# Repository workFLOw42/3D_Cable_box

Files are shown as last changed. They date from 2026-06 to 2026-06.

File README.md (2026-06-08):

# Kabelbox – frei konfigurierbar (Voronoi, entnehmbare Wände)

**Eigenentwicklung** in OpenSCAD + Python. Eine Box mit **4 entnehmbaren
Voronoi-Wänden**, **glattem Schiebedeckel** und je Wand wählbarem **Kabelloch**.
Design-Vokabular wie der Zahnbürstenhalter (gerundet R5, 5-mm-Füße, Schiebe-Mechanik,
bündig/keine Überstände).

> **Entwickeln/Weiterarbeiten:** Stand, Parameter, Build-Ablauf und Stolpersteine
> stehen in **[`DEVNOTES.md`](DEVNOTES.md)**.

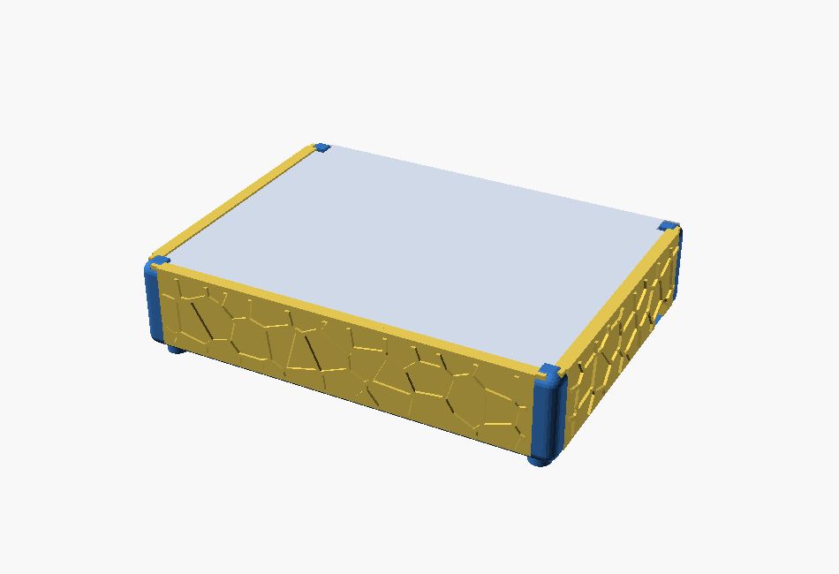
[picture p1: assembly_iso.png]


## Über dieses Projekt

**Warum gibt es die Kabelbox?**
Steckdosenleisten, Netzteile und Kabelsalat verschwinden am besten in einer Box – aber
die meisten fertigen Boxen sind in genau einer Größe gegossen und innen schlecht
zugänglich. Diese Box ist deshalb von Grund auf **frei konfigurierbar**: Breite, Tiefe
und Höhe sowie die Kabeldurchführungen werden in einer einzigen Parameterdatei
(`params.scad`) festgelegt, der gesamte Korpus skaliert automatisch mit.

**Idee dahinter.**
Die Box folgt einem bewussten Design-Vokabular (geteilt mit dem Schwester-Projekt
[„Elektrischer Zahnbürstenhalter"](https://github.com/workFLOw42/3D_OralB_Sonicare_toothbrush_holder)):
rundum **gerundete Kanten (R5)**, **bündige
Außenflächen ohne Überstände**, ein **erhabenes Voronoi-Relief** als Optik *und*
Materialersparnis sowie eine **werkzeuglose Schiebe-Mechanik**. Die vier Wände sind
einzeln **entnehmbar** und der Deckel gleitet von hinten ein – so kommt man jederzeit an
den Inhalt, ohne etwas aufzubrechen.

**Reproduzierbar statt Einmal-Export.**
Es handelt sich um eine **Eigenentwicklung**; alle Teile entstehen reproduzierbar aus
OpenSCAD-Quellen + Python-Generatoren (Voronoi, 3MF-Packen). Wer andere Maße braucht,
ändert die Parameter und baut neu – oder nutzt die MakerWorld-Einzeldatei mit Customizer.

**Status.** **Version 1.0** – funktionsfähig und gedruckt-verifiziert. Das jetzige
Aussehen ist der Startpunkt; das Projekt wird **bei Bedarf aktiv weiterentwickelt,
überarbeitet und erweitert**. Rückmeldungen, Ideen und Probedruck-Erfahrungen sind
willkommen.

## Konzept
- **Rahmen** (`box.scad`, bleibt fest): gerundeter Boden + **4 Eckpfosten** (flush
  in den Ecken) + **4 Füße**. Jeder Pfosten hat **2 senkrechte Nuten** für die
  angrenzenden Wände. Die Nuten liegen **bündig in den Pfosten** (Front-Skin) →
  nichts steht über; die Box-Außenkontur bleibt exakt B×T.
- **4 Wände** (`wall.scad`): **solide** Wand mit **erhabenem Voronoi-Relief** (wie
  Zahnbürstenhalter), gleiten senkrecht in die Pfosten-Nuten → **entnehmbar**.
  Außenfläche bündig (Relief steht – wie beim Holder – `relief_h` nach außen über).
  Je Wand optional ein **nach unten offener Kabel-Schlitz** (keins/links/mitte/rechts).
- **Deckel** (`lid.scad`): **glatte** Platte. Front/Links/Rechts tragen oben eine
  nach innen überstehende **Lippe** → der Deckel ist **3-seitig gefangen** und gleitet
  **von hinten** darunter ein. Die **Rückwand ist niedriger** (um `lid_t+lid_lip_t+
  lid_clear`) → der Deckel **läuft über die Rückwand** und schließt hinten **bündig**
  (y=box_d) ab. Oberseite leicht versenkt (unter den Lippen). Eck-Aussparungen für
  die Pfosten. *Entnahme: Deckel nach hinten herausschieben.*
- **Montage**: Wände von oben in die Pfosten-Nuten → Deckel von hinten unter die
  3 Lippen einschieben. Demontage umgekehrt.

## Maße (editierbar)
| | Wert |
|---|---|
| Box außen | **`box_w` × `box_d` × `box_h` = 200 × 150 × 41,8 mm** (+5 mm Füße) · **35 mm lichte Nutzhöhe** (Boden bis Deckel) |
| Wandstärke / Boden | 3 / 3 mm · Eckpfosten 10 mm · Kanten R5 |
| Kabel-Schlitz | `cable_w`=12 mm breit, unten offen, Oberkante `cable_h`=12 mm |

Position je Wand: **mitte** = exakt mittig; **links/rechts** = ein Lochbreiten-
Abstand zum inneren Rand.

## MakerWorld (Customizer)
Einzeldatei **`kabelbox_makerworld.scad`** hochladen (alle Module inline).
- **Maße**: `box_w` / `box_d` / `box_h`.
- **Kabelloch je Wand**: `cable_front/back/left/right` ∈ none/left/center/right.
- **Teil-Auswahl** `part`: `montage` (Vorschau) · `platte` (alle Teile nebeneinander)
  · `box` · `lid` · `wall_front/back/left/right`.

> **X2D-Hinweis**: Korpus und Deckel sind bei 200 × 150 jeweils fast plattengroß –
> sie passen **nicht gemeinsam** auf eine 256 × 256-Platte. Dann Teile einzeln
> wählen (2 Platten) **oder** die Box kleiner konfigurieren. `part="platte"` ist
> für kleinere Boxen gedacht.

## Bauen (lokal)
```
# Toolchain: OpenSCAD + Python (numpy, scipy, trimesh)
powershell -File build.ps1   # Voronoi -> STL -> 3MF -> Vorschau
```
Quelle: `params.scad` (Wahrheitsquelle) · `voronoi.scad` · `voronoi_data.scad` (auto)
· `box.scad` · `wall.scad` · `lid.scad` · `assembly.scad`. Werkzeuge: `gen_voronoi.py`,
`pack_3mf.py`, `build.ps1`.

## Drucken
- **Korpus**: offen nach oben, Füße unten – ohne Stützen.
- **Wände/Deckel**: flach liegend – ohne Stützen.
- **Spiele** nach Probedruck justieren: `rail_clear` (Wand↔Nut), `lid_clear` (Deckel).

## Lizenz

[CC BY-NC 4.0](LICENSE) – Namensnennung, keine kommerzielle Nutzung.

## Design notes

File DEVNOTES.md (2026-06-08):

# DEVNOTES – Kabelbox_frei_Konfig (Stand v1.0)

Arbeitsnotizen für die **Wiederaufnahme**. Kurz, aber vollständig.

## Status
**v1.0, funktionsfähig & verifiziert.** Eigenentwicklung (OpenSCAD + Python),
Design-Vokabular wie der Zahnbürstenhalter-Halter (`Elektr_Zahnbuerstenhalter_frei_Konfig`).

## Build / Werkzeuge
- **Build:** `powershell -File build.ps1` im Projektordner (nutzt `$PSScriptRoot`,
  also pfad-unabhängig). Erzeugt Voronoi-Daten, alle STLs, 3MF und die Vorschau.
- **Werkzeuge:** OpenSCAD (Windows-Default `C:\Program Files\OpenSCAD\openscad.exe`),
  Python mit numpy/scipy/trimesh.
- **Hinweis (lokale Eigenheit):** Wird der Ordner über OneDrive synchronisiert,
  können direkte Datei-Schreibzugriffe fehlschlagen — dann in einem lokalen Ordner
  bauen und die Ergebnisse per `Copy-Item` zurückkopieren.

## Architektur (Koordinaten: x=Breite, y=Tiefe [Front y=0, Rück y=box_d], z=Höhe)
- `params.scad` = **einzige Wahrheitsquelle** (Maße, Belegung, Feder/Nut, Deckel, Voronoi).
- `box.scad` = **Rahmen** (bleibt fest): gerundeter Boden + 4 Eckpfosten (flush) mit je
  2 senkrechten Wand-Nuten + Boden, 4 Füße. `place_wall(side)` platziert local→Seite
  (auch für Wände/Deckel genutzt). Top via `round_env()` gerundet.
- `wall.scad` = **1 entnehmbare Wand**, parametrisch je Seite. Solide + erhabenes
  Voronoi-Relief. Federn an den Enden → Pfosten-Nuten. Front/Links/Rechts: **Lippe**
  oben (`lid_lip`); **Rückwand: niedriger** (`wall_height("back")`). Kabel-Schlitz unten offen.
- `lid.scad` = **glatter Deckel**, 3-seitig unter den Lippen gefangen, hinten bündig,
  Eck-Aussparungen für Pfosten.
- `voronoi.scad` (reuse) + `voronoi_data.scad` (auto via `gen_voronoi.py`).
- `assembly.scad` (Vorschau), `pack_3mf.py`, `kabelbox_makerworld.scad` (Einzeldatei).

## Schlüssel-Parameter (params.scad)
- Maße: `box_w=200, box_d=150, box_h=41.8` (editierbar; 35 mm nutzbar Boden→Deckel),
  `wall_t=3, floor_t=3, post_sz=10, fillet_r=5`.
- Feder/Nut Wand↔Pfosten: `front_skin=1` (Skin vor Feder → flush), `tongue_d=4`,
  `rail_clear=0.3`, `rail_lead=1.2`.
- Deckel: `lid_t=2.5`, `lid_lip_t=1.0` (Lippen-Überdeckung), `lid_ov=3.0` (Lippe nach innen),
  `lid_clear=0.3`. Rückwand-Absenkung = `lid_t+lid_lip_t+lid_clear = 3.8`.
- Kabelloch: `cable_w=12`, `cable_h=12` (Oberkante über Boden), **unten offen**.
  Belegung: `cable_front/back/left/right` ∈ none/left/center/right.
  Position: center=mittig; left/right = 1 Lochbreite Abstand zum inneren Rand.
- Voronoi: `voro_seed=11, voro_cell=14, voro_strut=1.8, relief_h=1.2`.

## 1. Kiste (aktuell gesetzt, vom Nutzer bestätigt)
`cable_right="right"` (rechte Wand, Loch **hinten**, Welt-y≈122) +
`cable_back="right"` (Rückwand, Loch **links**/−x, Welt-x≈28). Front/Links = none.

## Verifiziert (contains-Tests)
- Box-Außenkontur exakt 200×150 (Füße bis z=−5) → **nichts steht über**.
- Wand-Feder sitzt in **flush** Pfosten-Nut; Front-Skin bleibt.
- (v1.1, Welt-Z am Assembly) Boden-Oberkante z=3,0; Deckel-Unterkante z=38,0
  → **35,0 mm nutzbar** (STL-Bounds verifiziert). Deckel z 38,0–40,5 (versenkt <41,8),
  hinten y=150 bündig; Rückwand-Oberkante z=38,0 (= niedriger, Deckel läuft drüber),
  Front/Links/Rechts z=41,8.

## Gotchas (WICHTIG)
- **Windows OpenSCAD `-D string="..."` reicht KEINE Strings durch** (→ undef)! Deshalb:
  Wand-STLs via **numerischen Index** `-D wi=0..3` (build.ps1). Auch `part`/`side`/`cable_*`
  lassen sich per CLI **nicht** als String setzen → Konfig nur via Datei/Customizer testen
  (oder Wert per `sed` in eine Temp-Datei backen).
- **X2D-Platte:** bei 200×150 passen **Korpus + Deckel NICHT zusammen** auf 256×256
  (Platte misst ~412–682). → Teile einzeln (2 Platten) oder Box kleiner. `part="platte"`
  ist für kleinere Boxen / Auto-Anordnung in Bambu Studio gedacht.
- **Voronoi** ist für die Default-Maße vorberechnet → bei Maßänderung `gen_voronoi.py` neu.
- Relief steht (wie beim Holder) `relief_h` nach außen über (Box dadurch +~2,4 mm).

## Offene Punkte / mögliche nächste Schritte
- **Deckel-Sicherung:** aktuell gleitet der Deckel zur Entnahme nach hinten heraus
  (gefangen nur in Z durch die Lippen). Falls gewünscht: kleiner **Rast-Nupsi** in den
  L/R-Lippen, der ihn in Endlage hält.
- **Probedruck-Feintuning:** Spiele `rail_clear` (Wand↔Nut) und `lid_clear` (Deckel)
  ggf. ±0,1 mm.
- **platte-Layout** ist simpel (nebeneinander); bei Bedarf kompakter packen.

## Build-/Verifikations-Ablauf
1. `params.scad` anpassen → `python gen_voronoi.py` (falls Maße/Voronoi geändert).
2. `powershell -File build.ps1` → box.stl, wall_{front,back,left,right}.stl, lid.stl,
   3MF, assembly_iso.png.
3. MakerWorld-Datei neu erzeugen (Bash-Concat, siehe Befehl in der Git-Historie /
   unten*) wenn `params/box/wall/lid` geändert.
4. Per PowerShell `Copy-Item` nach `…\Github\Kabelbox_frei_Konfig`.

*MakerWorld-Concat: alle Quellen ohne `include/use` und ohne Top-Level-Aufrufe
(`box();`,`lid();`,`wall(`,`side =`,`wi =`) zusammenfügen, Customizer-Header + Render-
/Teil-Auswahl (`part`: montage/platte/box/lid/wall_*) anhängen.

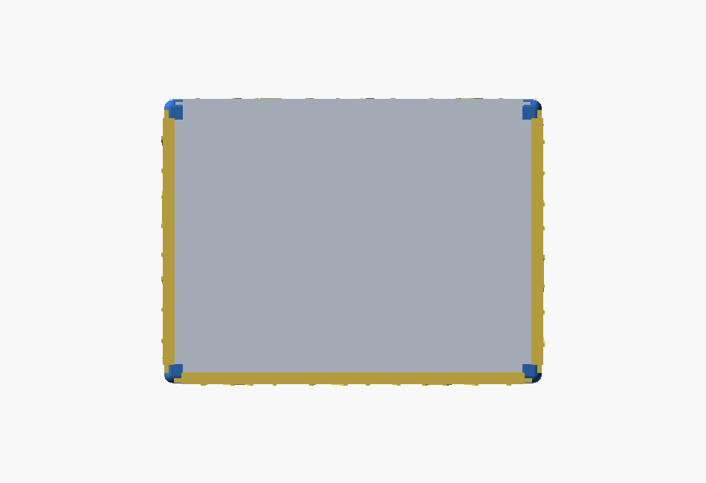
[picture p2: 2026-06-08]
doc_top.png

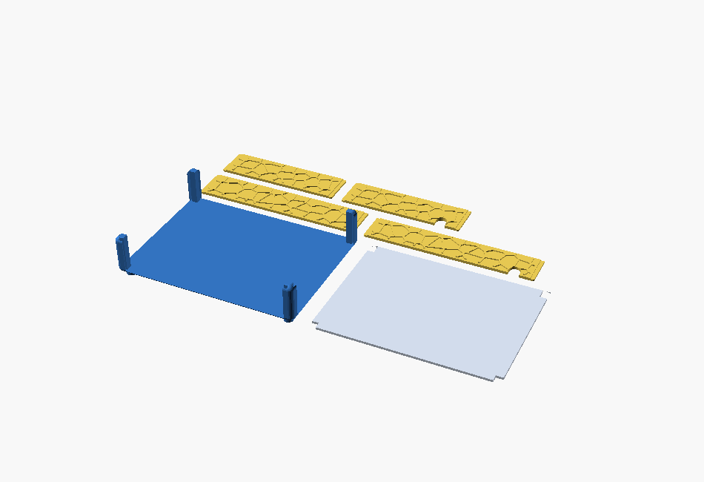
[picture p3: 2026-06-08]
doc_platte.png

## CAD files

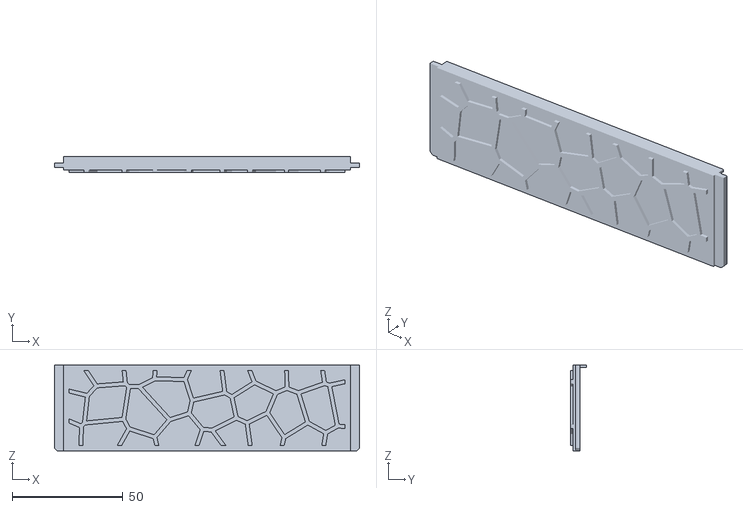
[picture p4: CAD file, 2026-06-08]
wall_left.stl
138.0 x 7.20 x 38.8

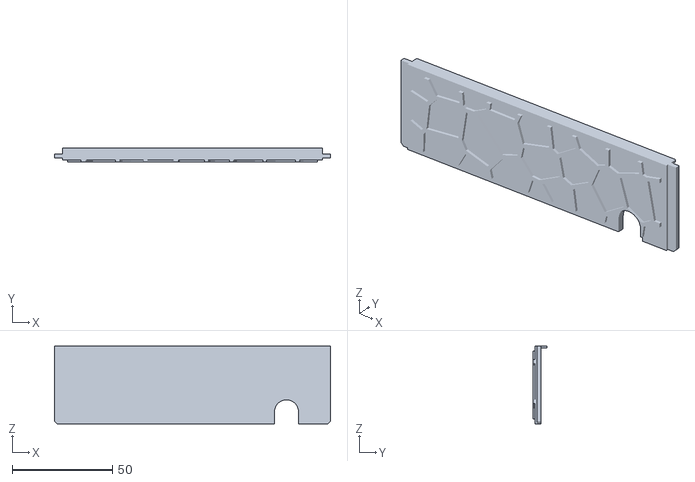
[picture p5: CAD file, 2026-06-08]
wall_right.stl
138.0 x 7.20 x 38.8

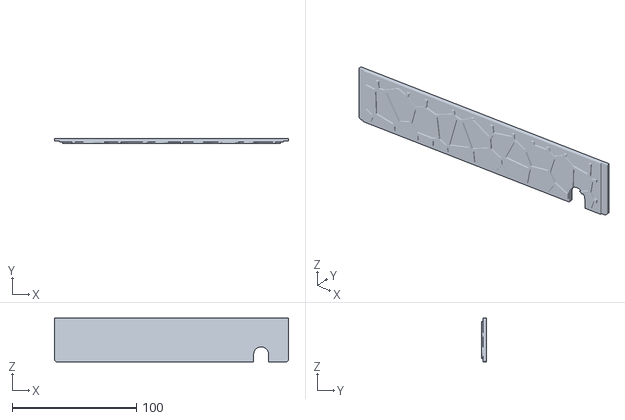
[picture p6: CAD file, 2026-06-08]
wall_back.stl
188.0 x 4.20 x 35.0

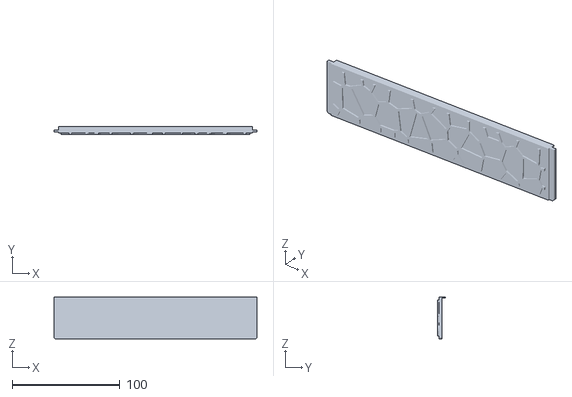
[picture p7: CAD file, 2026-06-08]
wall_front.stl
188.0 x 7.20 x 38.8

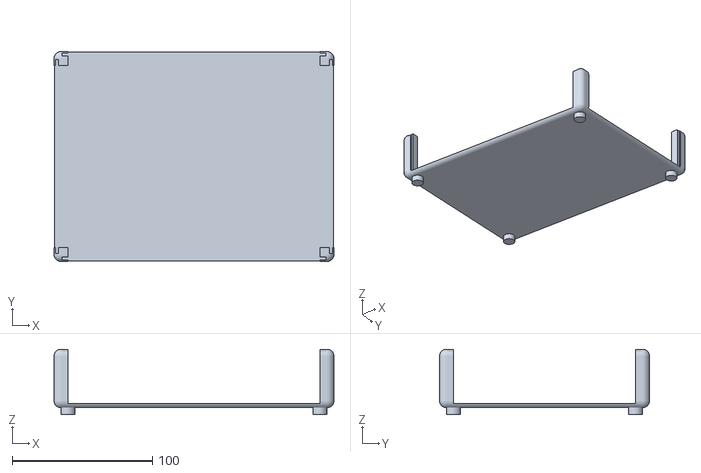
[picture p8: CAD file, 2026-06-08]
box.stl
199.9 x 149.9 x 46.8

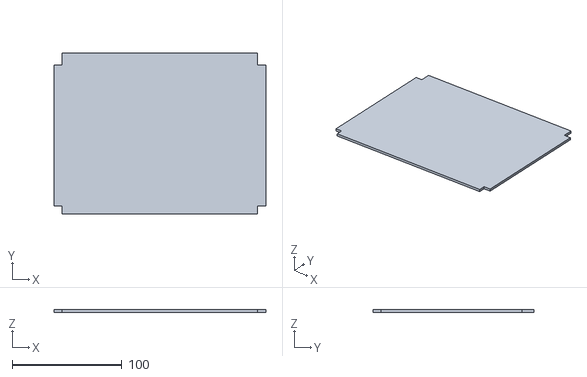
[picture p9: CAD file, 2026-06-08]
lid.stl
193.4 x 146.7 x 2.50

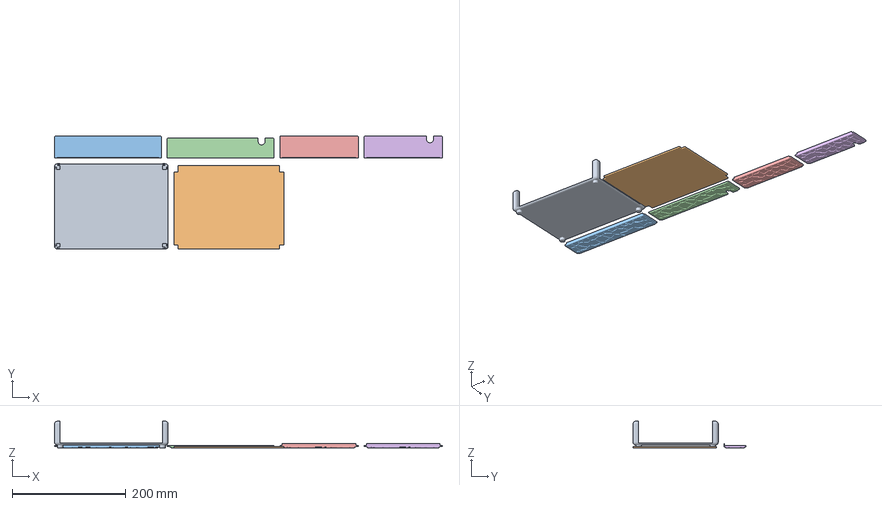
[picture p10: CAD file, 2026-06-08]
Kabelbox_frei_Konfig.3mf
682.0 x 198.7 x 46.8 mm
Korpus
Deckel
Wand_front
Wand_back
Wand_left
Wand_right

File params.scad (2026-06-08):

// =====================================================================
//  params.scad  -  Kabelbox, frei konfigurierbar (einzige Wahrheitsquelle)
//  Koordinaten: x=Breite, y=Tiefe (Front y=0, Rück y=box_d), z=Höhe.
//  4 Eckpfosten (flush) mit Nuten -> 4 entnehmbare Voronoi-Wände;
//  glatter Schiebedeckel von hinten; Füße; alles bündig.
// =====================================================================

/* [Maße] */
box_w = 200;   // Breite X (mm)
box_d = 150;   // Tiefe Y (mm)
box_h = 41.8;  // Höhe Z (mm, ohne Füße) -> 35 mm nutzbar (Boden bis Deckel)

/* [Kabellöcher je Wand] */
//  none = keins | left/center/right = Position (unten offener Schlitz)
cable_front = "none";   // [none:keins, left:links, center:mitte, right:rechts]
cable_back  = "right";  // [none:keins, left:links, center:mitte, right:rechts]  (1. Kiste)
cable_left  = "none";   // [none:keins, left:links, center:mitte, right:rechts]
cable_right = "right";  // [none:keins, left:links, center:mitte, right:rechts]  (1. Kiste)

// ---- Struktur -------------------------------------------------------
wall_t     = 3.0;   // Wandstärke (Außenfläche bündig)
floor_t    = 3.0;   // Bodenstärke
fillet_r   = 5.0;   // Kantenrundung R5 (wie Holder)
post_sz    = 10.0;  // Eckpfosten-Bein (X=Y), flush in der Ecke
foot_r     = 5.0;   // Fuß
foot_h     = 5.0;
foot_inset = 5.0;

// ---- Feder & Nut: Wand <-> Pfosten ----------------------------------
//  Feder (Rippe) sitzt hinter einer Front-Skin des Pfostens -> flush & in
//  Querrichtung gefangen (Prinzip wie Holder-Rückwand).
front_skin = 1.0;   // Pfosten-Skin vor der Feder (Außenseite)
tongue_d   = 4.0;   // Federtiefe in den Pfosten (Längsrichtung der Wand)
rail_clear = 0.3;   // Spiel Feder<->Nut
rail_lead  = 1.2;   // 45°-Einführfase unten an der Feder

// ---- Deckel (glatt, von hinten eingeschoben) ------------------------
//  Vorne/links/rechts: Lippe übergreift den Deckelrand (3-seitig gefangen);
//  Rückwand niedriger -> Deckel läuft drüber, schließt hinten bündig ab.
lid_t      = 2.5; // Deckeldicke
lid_lip_t  = 1.0; // Höhe/Überdeckung der Lippe über dem Deckelrand
lid_ov     = 3.0; // Lippen-Überstand nach innen (Deckel-Eingriff)
lid_clear  = 0.3; // Spiel Deckel

// ---- Kabelloch (unten offen, wie Zahnbürstenhalter) -----------------
cable_w = 12;   // Schlitzbreite (X entlang der Wand)
cable_h = 12;   // Oberkante des Schlitzes über dem Boden (Z)

// ---- Voronoi (Wand-Relief) ------------------------------------------
voro_seed  = 11;
voro_cell  = 14;    // Zellabstand Wand-Relief
voro_strut = 1.8;   // Stegbreite
relief_h   = 1.2;   // Reliefhöhe (erhaben)

// ---- abgeleitete Maße / Helfer (NICHT ändern) -----------------------
// lichte Spannweiten zwischen den Pfosten
span_w = box_w - 2*post_sz;   // Front/Rück-Wandlänge (X)
span_d = box_d - 2*post_sz;   // Links/Rechts-Wandlänge (Y)
wall_h = box_h - floor_t;     // Wandhöhe über dem Boden

$fn = 32;

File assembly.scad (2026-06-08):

// =====================================================================
//  assembly.scad  -  Vorschau: Rahmen + 4 Wände + Deckel (nur Ansicht)
// =====================================================================
include <params.scad>
include <voronoi_data.scad>
use <voronoi.scad>
use <box.scad>
use <wall.scad>
use <lid.scad>

color([0.20, 0.45, 0.75]) box();
for (s = ["front", "back", "left", "right"])
    color([0.90, 0.78, 0.32]) place_wall(s) wall(s);
color([0.82, 0.86, 0.92]) lid();

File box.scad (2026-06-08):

// =====================================================================
//  box.scad  -  Rahmen der Kabelbox (bleibt fest):
//   gerundeter Boden + 4 Eckpfosten (flush) mit je 2 senkrechten Wand-Nuten,
//   4 Füße. Nuten liegen INNERHALB der Pfosten (Front-Skin) -> flush.
// =====================================================================
include <params.scad>

module rounded_block(w, d, h, r) {
    minkowski() {
        translate([r, r, r]) cube([w - 2*r, d - 2*r, h - 2*r]);
        sphere(r = r, $fn = 24);
    }
}

// Platziert local (x=Länge 0..L, y=Dicke 0..wall_t [Außen y=0], z=Höhe 0..wall_h)
// auf die jeweilige Seite. L: front/back=span_w, left/right=span_d.
module place_wall(side) {
    if      (side == "front") translate([post_sz, 0, floor_t]) children();
    else if (side == "right") translate([box_w, post_sz, floor_t]) rotate([0,0,90]) children();
    else if (side == "back")  translate([box_w - post_sz, box_d, floor_t]) rotate([0,0,180]) children();
    else if (side == "left")  translate([0, box_d - post_sz, floor_t]) rotate([0,0,-90]) children();
}
function wall_len(side) = (side == "front" || side == "back") ? span_w : span_d;

// 4 Eck-Säulen (volle Höhe) – werden mit rounded_block geschnitten (runde Ecke)
module corner_cols() {
    for (cx = [0, 1], cy = [0, 1])
        translate([cx*(box_w - post_sz), cy*(box_d - post_sz), 0])
            cube([post_sz, post_sz, box_h + 1]);
}

// Nut-Schneider in local Wand-Koordinaten (schneidet die Pfosten an beiden Enden).
// Feder sitzt y∈[front_skin, wall_t]; Skin y∈[0,front_skin] bleibt -> flush.
module groove_cutter(L) {
    gy = wall_t + rail_clear - front_skin;       // Nuttiefe in Y
    for (e = [0, 1]) {
        gx = (e == 0) ? -tongue_d - rail_clear : L - 0.1;
        translate([gx, front_skin, 0])
            cube([tongue_d + rail_clear + 0.1, gy, wall_h + box_h]);
    }
}

module feet() {
    insets = foot_inset + foot_r;
    for (px = [insets, box_w - insets], py = [insets, box_d - insets])
        translate([px, py, -foot_h]) cylinder(h = foot_h + 0.5, r = foot_r, $fn = 36);
}

// Rundungs-Hülle (Top sauber runden, Relief/Füße nicht beschneiden)
module round_env() {
    e = 1.0;
    minkowski() {
        translate([fillet_r - e, fillet_r - e, fillet_r - foot_h - 1])
            cube([box_w - 2*fillet_r + 2*e, box_d - 2*fillet_r + 2*e,
                  box_h - 2*fillet_r + foot_h + 1]);
        sphere(r = fillet_r, $fn = 24);
    }
}

module box() {
    intersection() {
        difference() {
            union() {
                intersection() {
                    rounded_block(box_w, box_d, box_h, fillet_r);
                    union() {
                        cube([box_w, box_d, floor_t]);   // Boden
                        corner_cols();                    // 4 Pfosten
                    }
                }
                feet();
            }
            for (s = ["front", "back", "left", "right"])
                place_wall(s) groove_cutter(wall_len(s));
        }
        round_env();
    }
}

box();

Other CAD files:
kabelbox_makerworld.scad
lid.scad
voronoi.scad
voronoi_data.scad
wall.scad

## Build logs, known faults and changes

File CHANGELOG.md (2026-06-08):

# Changelog

Versionshistorie der frei konfigurierbaren Kabelbox. Maße in mm.

## [1.0] – 2026-06-08 · Erste Veröffentlichung

Frei konfigurierbare Kabelbox (Eigenentwicklung, OpenSCAD + Python), Design-Vokabular
wie der Zahnbürstenhalter (gerundet R5, 5-mm-Füße, Voronoi, Schiebe-Mechanik, bündig).
Reproduzierbar aus den Quellen baubar; MakerWorld-Einzeldatei mit Customizer enthalten.

### Funktionen
- **Rahmen** = gerundeter Boden + **4 Eckpfosten** (flush) mit je **2 senkrechten
  Wand-Nuten** (Nut bündig im Pfosten, Front-Skin → kein Überstand) + 4 Füße.
- **4 entnehmbare Voronoi-Gitterwände**, senkrecht in die Pfosten-Nuten geschoben.
- **Glatter Schiebedeckel**: Front/Links/Rechts mit nach innen überstehender **Lippe**
  (3-seitig gefangen), von hinten eingeschoben; **Rückwand niedriger** → Deckel läuft
  drüber, schließt hinten bündig ab; Eck-Aussparungen für die Pfosten; Oberseite leicht
  versenkt. Entnahme: nach hinten herausschieben.
- **Kabelloch je Wand** (none/left/center/right), nach unten offen (Stecker passt);
  mitte=exakt mittig, links/rechts=ein Lochbreiten-Abstand zum Rand.
- **Editierbar**: `box_w/box_d/box_h`; Korpus skaliert mit. Auslieferungsmaß
  **200 × 150 × 41,8 mm** (+5 mm Füße) → **35 mm lichte Nutzhöhe** (Boden bis Deckel).
- Wand-STL-Export via numerischem Index `wi` (Windows-`-D`-String-Bug umgangen).
- **MakerWorld**-Einzeldatei `kabelbox_makerworld.scad` (Customizer: Maße +
  Kabellöcher + Teil-/Platten-Auswahl).
- Arbeitsnotizen für Wiederaufnahme in **`DEVNOTES.md`**.

### Verifiziert
- Wand-Feder sitzt in der bündigen Pfosten-Nut (Front-Skin bleibt → flush),
  Box-Außenkontur exakt 200×150 (nichts steht über) – per `contains`-Test.
- Lichte Nutzhöhe **35,0 mm** (Boden z=3,0 → Deckel-Unterkante z=38,0) – per STL-Bounds.

### Hinweis
- Bei großen Boxen (z. B. 200×150) passen **Korpus + Deckel nicht gemeinsam** auf
  eine X2D-Platte (256×256) – dann Teile einzeln / 2 Platten oder Box kleiner.
- Voronoi für die Auslieferungsmaße vorberechnet; bei Maßänderung `gen_voronoi.py` neu.

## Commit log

2026-06-08 Initial release v1.0
    [Kabelbox_frei_Konfig.3mf, assembly.scad, box.scad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]
2026-06-08 Add .gitattributes (LF-Normalisierung, Binaerdateien)
    [box.stl, lid.stl, wall_back.stl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]
